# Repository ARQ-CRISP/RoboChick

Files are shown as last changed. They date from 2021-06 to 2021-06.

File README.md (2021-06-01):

# RoboChick

   All information needed to recreate RoboChick.

  RoboChick is an interactive robot capable of detecting and responding to chick behaviors. It was developed at Queen Mary University of London in order to provide a platform for identifying features that promote social interaction and filial imprinting in chicks. This repository contains all information needed to manufacture the basic version of RoboChick- with its simple, modular design, it can be easily customised depending on the requirements of the experiment. 

***

_**Contents:**_

**Code_RoboChick** code used in the basic version of RoboChick, written in Arduino, ran on Adafruit HUZZAH ESP8266 WiFi-enabled microcontroller. 

**Pages** code that renders the GUI website for setting up the experiment

**Components** complete list of components used build a single RoboChick

**ElectronicDesign** a full schematic of RoboChick hardware

**innerCase & outerCase** CAD files allowing to 3D print cases that were used to house the hardware of the robot.

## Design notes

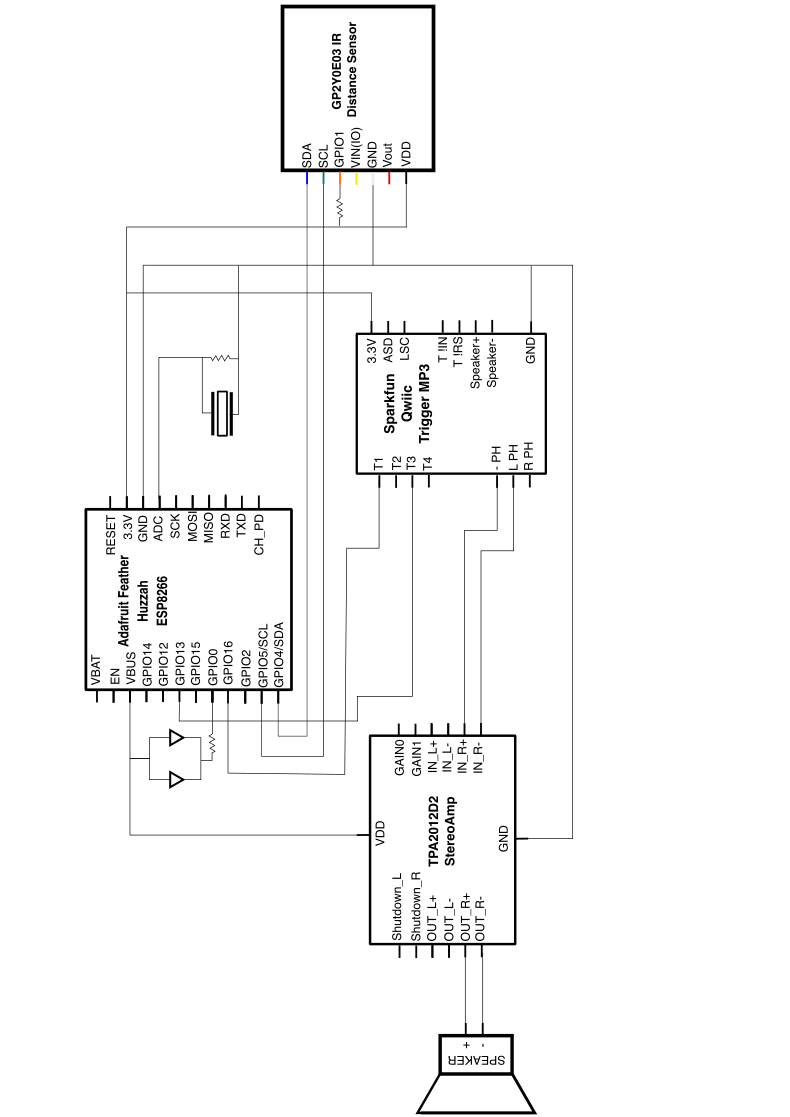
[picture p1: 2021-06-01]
electronicDesign.png

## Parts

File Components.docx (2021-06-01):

Microcontroller Adafruit Feather Huzzah ESP8266

Audio processor Sparkfun Qwiic MP3 trigger

Audio amplifier Adafruit Stereo 2.1W Class D Audio Amplifier

SD card SandDisk 16GB Class 10 Micro SD Card

Speaker 36mm Diameter 1W Miniature Speaker

LED 2x Light Emitting Diode 5mm 20mA 2-2.2v (red)

Proximity Sensor GP2Y0E03 IR Distance Sensor

Switch transistor ST Microelectronics BC548B

Touch sensor 15mm piezoelectric discs, generic

PVC printing material red and transparent

Stripboards generic stripboard

Jumper cables generic

Resistors generic, 1 MΩ, 100Ω, 47kΩ

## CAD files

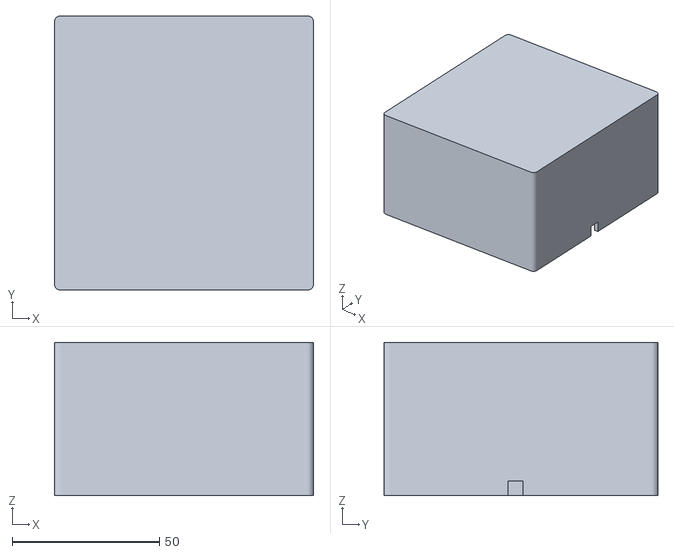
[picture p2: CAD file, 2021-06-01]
OuterCase.stl
88.0 x 93.0 x 52.0

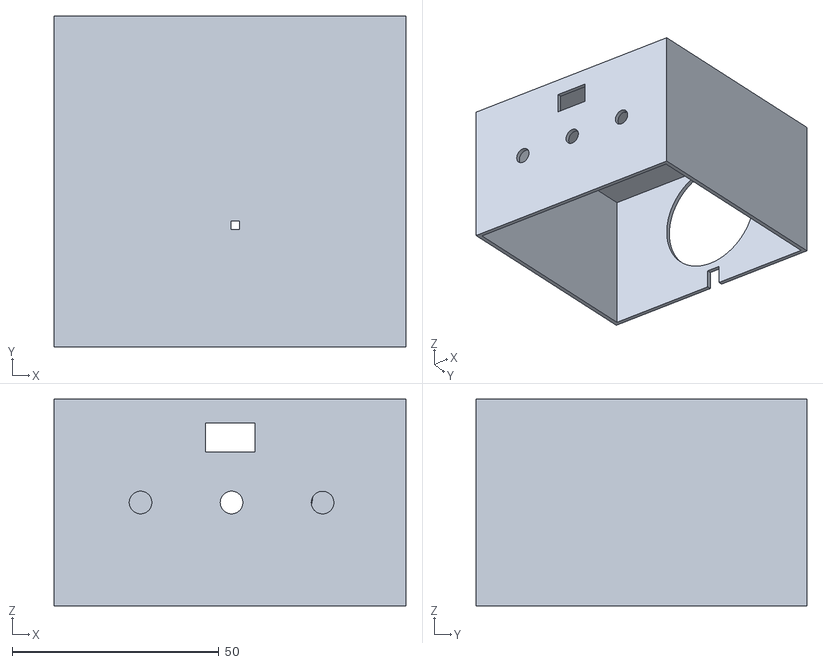
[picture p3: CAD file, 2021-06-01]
InnerCase.stl
85.0 x 80.0 x 50.0

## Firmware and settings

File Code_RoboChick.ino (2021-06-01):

#include <ESP8266WiFi.h>          // ESP8266 Core WiFi Library (you most likely already have this in your sketch)
#include <ESP8266WiFiMulti.h>     // Include the Wi-Fi-Multi library
#include <ESP8266WebServer.h>     // Local WebServer used to serve the configuration portal
#include <WiFiClient.h>
#include "pages.h"
#include <Wire.h>
#include <list>

#define SENSOR_ADDRESS 0x40 //I2C address of the proximity sensor (GP2Y0E03)
#define DISTANCE_ADDRESS 0x5E // data address of distance value


//PleasureChirps are on trigger 0
//DistressCalls are on trigger 1
enum eventType {peck, sound, vibrate, calibrate, approach, expStart, expEnd};
struct event{ // This class defines the type of events that are logged
  eventType category;
  String timestamp;
  String message;
};

struct experiment{          // This structure describes all the elements of the experiment (Peck detection)

  //initialize variables
  bool alive;               // Is the experiment running? 0=no 1=yes
  unsigned long startTime;  // When did the experiment start (timestamp in milliseconds since power was switched on)
  unsigned long proximityCheck; // time of the last proximity sensor check (timestamp in millis)
  unsigned long soundStart; //time when sound started (millis)
  int distance;             // Distance read from the proximity sensor (cm)
  bool activeCheck=0;
  bool sound= LOW; //LOW indicates sound is off
  unsigned long flashStart;     // timestamp when the previous flash started 
  unsigned long previousFlash; // timer for flashing lights
  unsigned long lastPeck;    // time when the last peck was detected (timestamp)
  byte dist[2];            // byte array for reading distance from the proximity detector

  //experimental settings (set via the online gui)
  unsigned long duration;   // How long is the experiment meant to last (in milliseconds)
  int sensitivity;          // Sensitivity of the tactile sensor (set via the online gui)
  bool Sound1;              // Option: Play sound 1 on detection of a peck 
  bool Sound3;              // Option: Play sound 2 (indexed as 3) on detection of a peck
  bool light;               // Option: Light in response to pecking
  bool flashing;            // Option: constant flashing light
  bool approachSound;       // Option: flash light when chick detected at a specified distance (set via the online gui) 
 
};

// Functions that will be defined later
void buzzDroid(int timeMS);
void handleVibrate();
void handleStop();
void startExperiment();
int readSensor();
int proximity();     //read proximity sensor             
void playSound1();   //distress
void playSound3();   //pleasure
String millisToString(unsigned long ms);
void handlePeck();
int calibrateSensor();
void flashLight();
void chickApproaching(); // proximity sensor detecting the chick
void check(); //turns off actions which are finished
event newEvent(eventType cat, String msg);
void reconnectWifi(); //reconnects to wifi if connection was lost

experiment expConfig;
int stableMeasurement;
std::list<event> events;
String minsIn;
String hrsIn;
bool pecked;
bool vibrating;

int motor = 12;
int Sound3 = 16;
int Sound1 = 13;
int stateFlash = LOW; 



//Declare a global object variable from the ESP8266WebServer class.
ESP8266WebServer server(8000); //Server on port 8000
ESP8266WiFiMulti wifiMulti;     // Create an instance of the ESP8266WiFiMulti class, called 'wifiMulti'

//===============================================================
// This routine is executed when you open the IP:port\routine in browser- in order to start the experiment, IP:port needs to be open in browser
//===============================================================
void mainPage() // What to do when main page called?
{
  String s = MAIN_pageS; //Read HTML contents of header
  if (expConfig.alive) // Print status of experiment
  {
    s = s + "Experiment is running<br>";
  }
  else
  {
    s = s+ "Experiment is not running<br><br>";
  }
  s = s + MAIN_pageE; // Add end of HTML page
  server.send(200, "text/html", s); //Send web page
}

void handleRoot()
{
  Serial.println(F("You called root page"));
  mainPage();
}

void handleViewConfig() // This happen when we choose to view current experiment status
{
  Serial.println(F("You asked to see current experiment"));
  if (expConfig.alive)
  {
    String page;
    page = CONFIG_pageS;
    page = page + "Duration - " + hrsIn + ":" + minsIn + "<br>";
    page = page + "Threshold - " + expConfig.sensitivity + "<br>";
    if (expConfig.vibration)
    {
      page = page + "Vibration pulse of length " + expConfig.pulseLength + "ms" "<br>";
    }
    if (expConfig.Sound1)
    {
      page = page + "Sound 1<br>";
    }
    else if (expConfig.Sound3)
    {
      page = page + "Sound 2<br>";
    }
    page = page + RESULTS_pageE;
    server.send(200, "text/html", page);
  }
  else
  {
    server.send(412, "text/html", "Experiment not running - go back and start an experiment");
  }
}


void refreshResults()
{
  String s = RESULTS_pageS; //Read HTML contents
  String results;
  for (event e:events) // It loads all events and prints them
  {
    results = results + String(e.timestamp);
    results = results + String(e.message);
    results = results + "<br>";
  }
  s = s + results + RESULTS_pageE;
  server.send(200, "text/html", s); //Send web page
}

void handleResults() // This happens when results are requested
{
  Serial.println(F("Results page"));
  String s = RESULTS_pageS; //Read HTML contents
  Serial.println(F("results head loaded"));
  String results;
  for (event e:events) // It loads all events and prints them
  {
    results = results + String(e.timestamp);
    results = results + String(e.message);
    results = results + "<br>";
  }
  Serial.println(F("results loaded"));
  s = s + results + RESULTS_pageE;
  Serial.println(F("page build complete"));
  server.send(200, "text/html", s); //Send web page
  Serial.println(F("page sent"));
}

void handleSound3()
{ // When this Sound is requested
  Serial.println(F("Sound 3 (4?) manually played"));
  mainPage();
  //playSound4();
}

void handleSound2()
{
  Serial.println(F("Sound 2 manually played"));
  mainPage();
  playSound3();
}

void handleSound1()
{
  Serial.println(F("Sound 1 manually played"));
  mainPage();
  playSound1();
}

void handleVibrate()
{
  Serial.println(F("Vibration activated manually"));
  mainPage();
  buzzDroid(expConfig.pulseLength);
}

void handleStop() // When stop request of experiment
{
  Serial.println(F("experiment ended"));
  expConfig.alive = false;
  if(expConfig.sensitivity == 0)
  {
    analogWrite(motor, 0);
    vibrating = false;
  }
  mainPage();
}

void handleCalibrate() // Manual calibration request
{
  Serial.println(F("Recalibration requested"));
  stableMeasurement = calibrateSensor();
  mainPage();
  Serial.print(F("Sensor recalibrated to "));
  Serial.println(stableMeasurement);
}

void startExperiment() // Start experiment request
{
  String s = EXPERIMENT_page; //Read HTML contents
  server.send(200, "text/html", s); //Send web page
}

void handleForm() // This function receives experiment form and configures experiment
{
  if(server.arg("lengthHR") == NULL){
    minsIn = server.arg("lengthMIN");
    expConfig.duration = (minsIn.toInt())*60000;
  }
  else if(server.arg("lengthMIN") == NULL){
    hrsIn = server.arg("lengthHR");
    expConfig.duration = (hrsIn.toInt())*3600000;
  }
  else {
    minsIn = server.arg("lengthMIN");
    hrsIn = server.arg("lengthHR");
    unsigned long mins = minsIn.toInt();
    unsigned long hrs = hrsIn.toInt();
    expConfig.duration = hrs*3600000 + mins*60000;
  }
  
  expConfig.sensitivity = server.arg("sensitivity").toInt();
  expConfig.pulseLength = server.arg("vibrateLength").toInt();

  expConfig.pauseLength = 0;
  
  // enable/disable 
  if (server.arg("responseVibrate")=="V"){
    expConfig.vibration = true;
    expConfig.intensity = 100 + (server.arg("vibrateIntensity").toInt() * 1.5);
    if(expConfig.sensitivity == 0){
      expConfig.pauseLength = server.arg("pauseLen").toInt();
    }
  }
  else{
    expConfig.vibration = false;
  }
  if (server.arg("responseS1")=="S1"){
    expConfig.Sound1 = true;
    expConfig.Sound3 = false;
  }
  else{
    expConfig.Sound1 = false;
  }
  if (server.arg("responseS2")=="S2"){
    expConfig.Sound3 = true;
    expConfig.Sound1 = false;
  }
  else{
    expConfig.Sound3 = false;
  }
  if (server.arg("light")=="L"){
    expConfig.light = true;
  }
  else{
    expConfig.light = false;
  }

  if (server.arg("flashing")=="F"){
    expConfig.flashing = true;
    expConfig.light = false;
    expConfig.flashStart=0;
  }
  else{
    expConfig.flashing = false;
  }
  
  if (server.arg("approachSound")=="A1"){
    expConfig.approachSound= true;
  }
  else {
    expConfig.approachSound= false;
  }
 

  expConfig.alive = true;               //enable experiment behaviour
  pecked = false;                       //Not being pecked at experiment start
  
  expConfig.startTime = millis();                 //log experiment start time
  
  events.push_back(newEvent(expStart, " - experiment start"));
  Serial.println(F("experiment start logged"));

  String chick= server.arg("chickID");
  String date= server.arg("date");
  String arena= server.arg("arena"); 
  
  Serial.println(date + "_arena_" + arena + "_chick_" + chick + '.');

  String s = SUCCESS_page;
  server.send(200, "text/html", s); //Send web page
  
}

//===============================================================
// This routine is executed when you turn on System
//===============================================================
void setup() {
  pinMode(0, OUTPUT); 
  pinMode(motor,OUTPUT);
  pinMode(Sound1, OUTPUT);
  pinMode(Sound3,OUTPUT);
  pinMode(A0, INPUT);
  digitalWrite(Sound3,LOW);
  digitalWrite(Sound1,LOW);
  digitalWrite(motor,LOW);
  digitalWrite(0,HIGH);
 

  expConfig.alive = false;

  
  //initialize I2C
  Wire.begin();
  delay(500); //start after 500ms
  
  Serial.begin(115200);
  delay(500);
  Serial.println("Serial connections online");  // Confirm serial online
 
  // We start by connecting to a WiFi network- FILL IN WITH THE DETAILS NEEDED FOR CONNECTION

 wifiMulti.addAP("NETWORK_NAME1", "PASSWORD1");
 wifiMulti.addAP("NETWORK_NAME2", "PASSWORD2");
 
 Serial.print("Connecting to wifi");

  while (wifiMulti.run() != WL_CONNECTED) { // Wait for the Wi-Fi to connect: scan for Wi-Fi networks, and connect to the strongest of the networks above
    delay(1000);
    Serial.print('.');
  }
 
  Serial.println();
  Serial.println();
  Serial.print(F("Connecting to "));
  
  Serial.println('\n');
  Serial.print(F("Connected to "));
  Serial.println(WiFi.SSID());              // Tell us what network we're connected to
  Serial.print(F("IP address: "));
  Serial.print(WiFi.localIP());     // Send the IP address of the ESP8266 to the computer
  
  server.on("/", handleRoot);       //Which routine to handle at root location. This is display page
  server.on("/experiment", startExperiment);
  server.on("/viewConfig", handleViewConfig);
  server.on("/sound1", handleSound1);
  server.on("/sound2", handleSound2);
  server.on("/sound3", handleSound3);
  server.on("/vibrate", handleVibrate);
  server.on("/expStop", handleStop);
  server.on("/calibrate",handleCalibrate);
  server.on("/results", handleResults);
  server.on("/config", HTTP_POST, handleForm);

  server.begin();                  //Start server
  Serial.println(F(" HTTP server started"));

  stableMeasurement = calibrateSensor();
  Serial.print(F("stable acceleration calibrated to "));
  Serial.println(stableMeasurement);

  vibrating = false;

  int counter=0;

}

//===============================================================
// This routine is executed constantly. Contains experiment (if enabled)
//===============================================================
void loop()
{
  ESP.wdtDisable();
  ESP.wdtFeed();

  int inst;
  int d;
  byte dist[2];
  
  //Serial.println("loop");
  server.handleClient();
  if ((expConfig.alive) && (millis()%10==0)) // If experiment active
  {
    d= proximity(); 
    inst = readSensor();
    int peckInterval=1000;
    if ((expConfig.sensitivity != 0) && (!pecked) && (abs(inst - stableMeasurement) > expConfig.sensitivity) && (millis()-expConfig.lastPeck >= peckInterval)) // Experiment when sensitivity is not 0
    {
      Serial.print(F("new peck detected: "));
      Serial.print(inst);
      Serial.print(F(" at "));
      Serial.println(millisToString(millis()));
      expConfig.lastPeck= millis();
      handlePeck();
    }
    else
    {
      pecked = false;
    }

    if (d==0) {
      d= Wire.requestFrom(SENSOR_ADDRESS, 2);
      dist[0]=Wire.read(); //
      dist[1]= Wire.read();
      expConfig.distance= ((dist[0] * 16 + dist[1]) / 16) / 4; // distance
      if (expConfig.distance < 30) {
        chickApproaching();
      }
      
    }
    
    if(expConfig.sensitivity == 0) // If sensitivity is 0 there is some sort of alternating behavior
    {
      unsigned long cycleLength = expConfig.pulseLength + expConfig.pauseLength;
      if((((millis() - expConfig.startTime)%cycleLength) < expConfig.pulseLength) && (!vibrating))
      {
        analogWrite(motor, expConfig.intensity);
        vibrating = true;
      }
      if((((millis() - expConfig.startTime)%cycleLength) > expConfig.pulseLength) && (vibrating))
      {
        analogWrite(motor, 0);
        vibrating = false;
      }
    }
    
    if ((millis() - expConfig.startTime) > expConfig.duration) // If timelimit reached, terminate the experiment
    {
      analogWrite(motor, 0);
      vibrating = false;
      expConfig.alive = false;
      events.push_back(newEvent(expEnd, " - experiment ended"));
      Serial.println("experiment ended");
    }
      if ((expConfig.flashing) && (expConfig.alive))
    {
      flashLight();
    }
  }

  if (expConfig.activeCheck==1){
    check();
  }
  yield();

}



void buzzDroid(int timeMS) // Handles motor vibration
{
  analogWrite(motor, expConfig.intensity); // Turns on vibration and also output is intensity
  delay(timeMS);
  analogWrite(motor, 0);
  if (expConfig.alive && expConfig.vibration){ // Push event
    events.push_back(newEvent(vibrate, " - vibration pulse of length " + String(timeMS) + "ms"));
  }
}




void playSound3(){
  if (expConfig.sound==LOW){
    expConfig.soundStart=millis();
    expConfig.sound=HIGH;
    digitalWrite(Sound3, HIGH);
    events.push_back(newEvent(sound, " - played pleasure sound"));
    expConfig.activeCheck= 1;
  }
}

void check(){
  if ((millis() - expConfig.soundStart) > 500UL){
    digitalWrite(Sound3, LOW);
    digitalWrite(Sound1, LOW);
    expConfig.sound=LOW;
    expConfig.activeCheck= 0;
  }
  
}

void playSound1(){
  if (expConfig.sound==LOW){
    expConfig.soundStart=millis();
    digitalWrite(Sound1, HIGH);
    expConfig.activeCheck= 1;
    expConfig.sound=HIGH;
  }
}

int readSensor(){ // Read value of sensor
  return analogRead(A0);
}

int proximity(){ //read proximity sensor
    Wire.beginTransmission (SENSOR_ADDRESS); //start communication
    Wire.write (DISTANCE_ADDRESS); // specify the addtess of the table storing the distance
    expConfig.distance= Wire.endTransmission();//close data
  }


String millisToString(unsigned long ms){ // Transform milisecond into something readable
  int hours = ((ms/1000) / (60 * 60)) % 24;
  int minutes = ((ms/1000) / 60) % 60;
  int seconds = (ms/1000)%60;
  return String(hours) + ":" + String(minutes) + ":" + String (seconds);
}



void flashLight(){ //light continuously flashing throughout the duration of the experiment. Change frequency by changing "interval" in expConfig
  int interval= 500;
  if (millis()-expConfig.flashStart >=interval) {
    expConfig.flashStart= millis();

    if (stateFlash == LOW) {
      stateFlash = HIGH;
    } else {
      stateFlash = LOW;
    }
    digitalWrite(0, stateFlash);
  }
}



void chickApproaching(){
  unsigned long proxInterval= 1500;
    if (millis()-expConfig.proximityCheck >= proxInterval) {
     expConfig.proximityCheck= millis();
      //events.push_back(newEvent(approach, " - chick approaching at " + (String(expConfig.distance)) + "cm"));
      //refreshResults();
      if ((expConfig.approachSound==true) && (expConfig.distance<=15)){
        playSound1();
              }
    }
}



void handlePeck(){ // What happens after peck detection
  events.push_back(newEvent(peck, " - peck detected"));

  if(expConfig.light){ // Would turn on light if needed
    digitalWrite(0, LOW);
  }
  if(expConfig.Sound1){
    playSound1();
  }
  else if(expConfig.Sound3){
    playSound3();
  }
   if(expConfig.vibration){
    buzzDroid(expConfig.pulseLength);
   }
  delay(100); // Wait a bit
  digitalWrite(0, HIGH); //Turn off light
  refreshResults();
}



int calibrateSensor(){
  int acc = 0;
  int inst;
  for(int i=0;i<100;i++){
    inst = readSensor();
    acc = acc + inst;
  }
   if (expConfig.alive){
    events.push_back(newEvent(calibrate, (" - recalibrated - " + (String(acc/100))))); // If recalibrated in the middle of experiment
  }
  return acc/100;
}

event newEvent(eventType cat, String msg){
  event newEvt;
  newEvt.category = cat;
  newEvt.timestamp = millisToString(millis() - expConfig.startTime);
  newEvt.message = msg;
  return newEvt;
}



void reconnectWifi() {
    Serial.print("Reconnecting to wifi");

  while (wifiMulti.run() != WL_CONNECTED) { // Wait for the Wi-Fi to connect: scan for Wi-Fi networks, and connect to the strongest of the networks above
    delay(1000);
    Serial.print('.');
  }
  Serial.print(F("Reconnecting to "));
  
  Serial.println('\n');
  Serial.print(F("Reconnected to "));
  Serial.println(WiFi.SSID());              // Tell us what network we're connected to
  Serial.print(F("IP address: "));
  Serial.print(WiFi.localIP());     // Send the IP address of the ESP8266 to the computer
  
}
